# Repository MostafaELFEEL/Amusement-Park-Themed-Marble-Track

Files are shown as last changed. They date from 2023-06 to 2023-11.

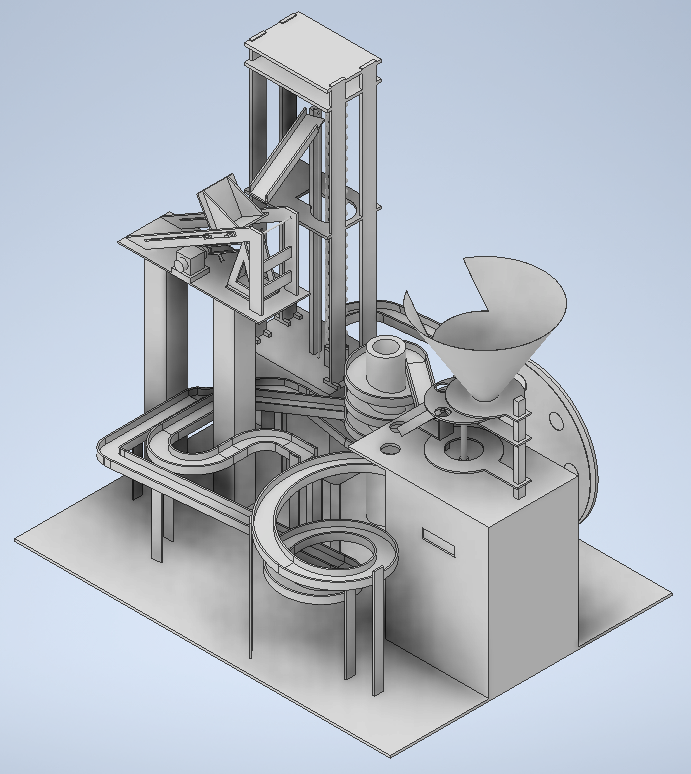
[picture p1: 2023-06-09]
Images of CAD+CAD file/3.PNG

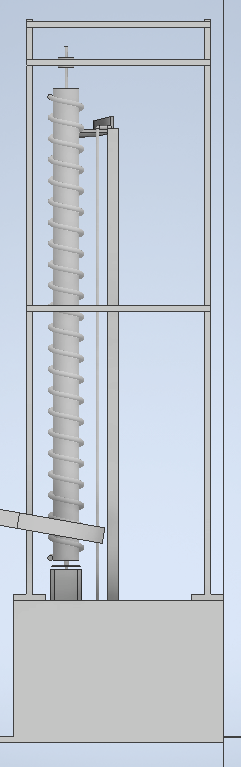
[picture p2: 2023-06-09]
Images of CAD+CAD file/elevator 1.PNG

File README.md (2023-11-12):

# Amusement Park Themed Marble Track
## Kid-Friendly Marble Track Design

Welcome to our exciting marble track, designed especially for kids. This closed-loop game takes the ball on a thrilling journey through various stages, ensuring hours of entertainment.

## Features
1. **Elevator:** The ball is lifted and guided by a fascinating elevator system.
2. **Shooting:** Experience the excitement as the ball is launched from a shooting mechanism.
3. **Sorting:** A sophisticated mechanism, complete with sensors and actuators, automatically categorizes balls into different tracks based on their colors.
4. **Pathways:** The sorted balls travel through engaging pathways, adding an extra layer of fun.

After completing the pathways, the sorted balls are collected and fed back into the elevator system, ensuring continuous enjoyment for the little ones.

## Project Details
For a deeper dive into the project, check out the [Google Drive link](https://drive.google.com/drive/folders/1FEB35v0lif-gc465zCmdioxmccTQT4f7?usp=drive_link) for additional details.

## Watch the Project in Action
- [YouTube Video](https://www.youtube.com/watch?v=VSdp7pH9CCw)
- [Additional Videos](https://drive.google.com/drive/folders/1bEXKJVpvYqGoTFXghtoVNARCpgTNY1nO?usp=drive_link)

Project Image

# CAD Design

CAD Design

Feel free to explore the project and witness the joy it brings to young minds!

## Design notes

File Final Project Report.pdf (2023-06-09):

AIN SHAMS UNIVERSITY
FACULTY OF ENGINEERING

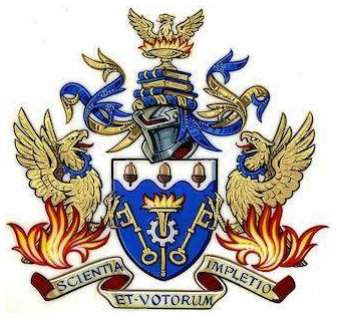
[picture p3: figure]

Mechatronics and Automation Engineering Programs (CHEP) Midterm
- Academic Year 2020/2021

Group 2 Section 1 subsection 2 Team 2
Youssef Khaled Mohamed | 18P2695
Mostafa Ashraf ELFEEL | 18P7611
Mohamed Sherif Shabaan | 18P5784
Youssef Ashraf Ahmed Mohamaden | 18P6536
Mohamed Sherif Mohamed Farid | 18P4006

UEL Module Code
EG8422

UEL Module Name
Machine Design

ASU Course Code
MCT 131

ASU Course Name
Introduction to Mechatronics

Semester
Fall 2020

Date of Submission
21/2/2021

AIN SHAMS UNIVERSITY
I-Credit Hours Engineering Programs (i.CHEP)
2 | P a g e

### Table of Content

I-Credit Hours Engineering Programs (i.CHEP)

3 | P a g e

### Table of figures

### Figure 1 | 6

### Figure 2 | 7

### Figure 3 | 8

### Figure 4 | 9

### Figure 5 | 10

### Figure 6 | 11

### Figure 7 | 12

### Figure 8 | 13

### Figure 9 | 14

### Figure 10 | 15

### Figure 11 | 16

### Figure 12 | 17

### Figure 13 | 20

### Figure 14 | 21

### Figure 15 | 25

### Figure 16 | 26

### Figure 17 | 27

I-Credit Hours Engineering Programs (i.CHEP)

4 | P a g e

### Abstract:

In this report we will discuss final project for MCT 131- introduction to mechatronics. Project details, design, manufacturing of ball sorting mechanism and applying of principles of design such as user experience, mind maps and mood board.

### Introduction:

Our project is a marble track for kids, it is a closed loop game which ball starts at the reservoir or anyplace then it goes through stages which is:

1- Elevator
2- Shooting
3- Sorting
4- Pathways

Ball sorting mechanism is designed to sort balls of 3 different colors into 3 different tracks by way of automatic system containing sensors and actuators.
The balls are then collected through pathways and fed into elevator system which lifts and guides the balls into a shooting mechanism. Then the balls after being shot are caught and delivered to sorting mechanism which sorts them, and the loop continue.

This was a brief overview of the game.

### Research

We got most of our ideas from asking older students and from these links: https://www.youtube.com/watch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 (https://howtomechatronics.com/tutorials/arduino/arduino-dc-motor-control-tutorial-l298n-pwm-h-bridge/)

I-Credit Hours Engineering Programs (i.CHEP)

5 | P a g e

### Work Planning

We divided the project into 3 stages…

Stage 3: Calibrating and Finishing

Upon completion of each mechanism, we started putting it together and calibrating

each mechanism to fit into the project. Then we started decorating the project to fit

into our theme

Stage 1: Brainstorming

We decided to brainstorm a general design that includes size, general positioning,

and an abstract flow of mechanisms.

Stage 2: Main Work Process

Then we started detailing and designing each mechanism separately but considering

the general design.

Stage 4: Integrating

After individually finishing each part we started working on integrating all parts

with each other

I-Credit Hours Engineering Programs (i.CHEP)

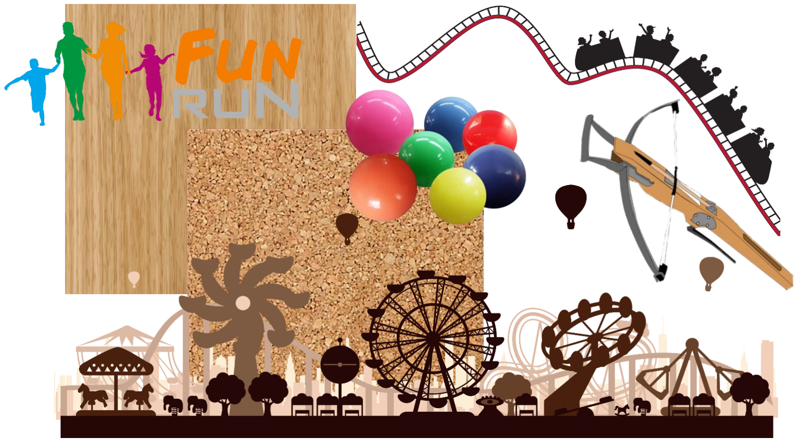
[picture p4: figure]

6 | P a g e

### Design and Theme

Theme:

Our chosen theme is “Amusement park” as this theme would provide us with several design ideas that would fit our project requirements.

Mood board:

Fig. 1: mood board design

I-Credit Hours Engineering Programs (i.CHEP)

7 | P a g e

Mind Map:

Minimum hight

2 Mechanisms

Strength

Target

3 way sorting | Match theme
| Match color of balls

Fig. 2: Mind map design

I-Credit Hours Engineering Programs (i.CHEP)

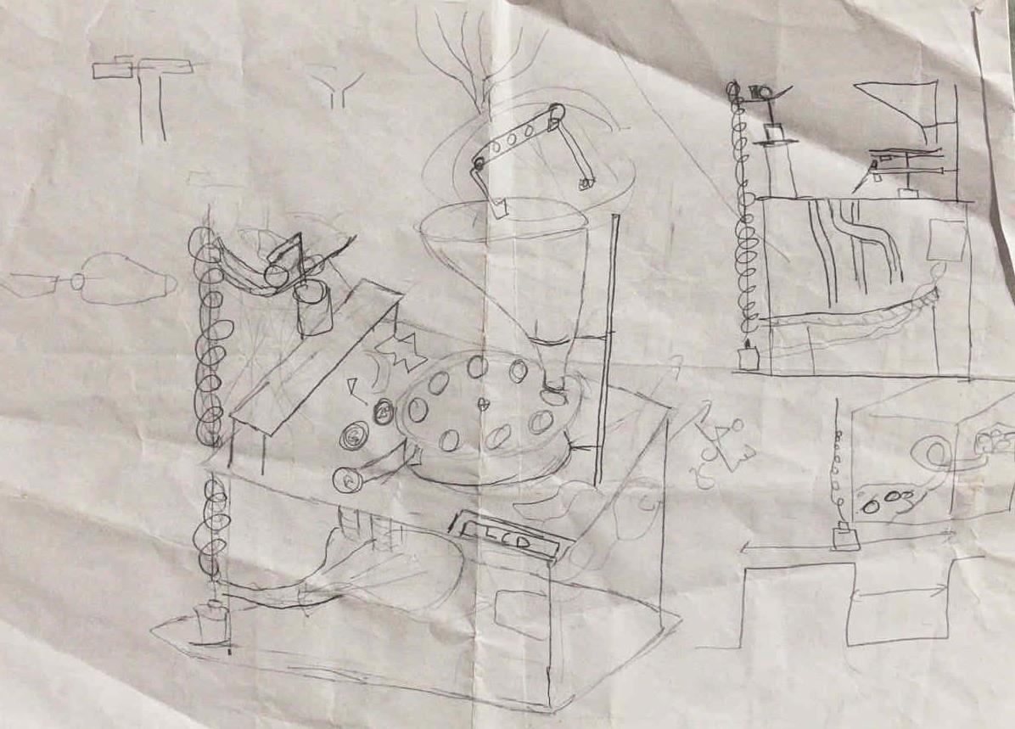
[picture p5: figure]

8 | P a g e

Fig. 3: image of draft drawing

First Draft of the general design:

We used this draft as a starting point to picture the positioning, size, theme and mechanisms.

I-Credit Hours Engineering Programs (i.CHEP)

9 | P a g e

Sketches:

Fig. 4-1: sketch of shooting mechanism

Fig. 4-2: sketch of lifting mechanism

Fig. 4-3: sketch of sorting mechanism

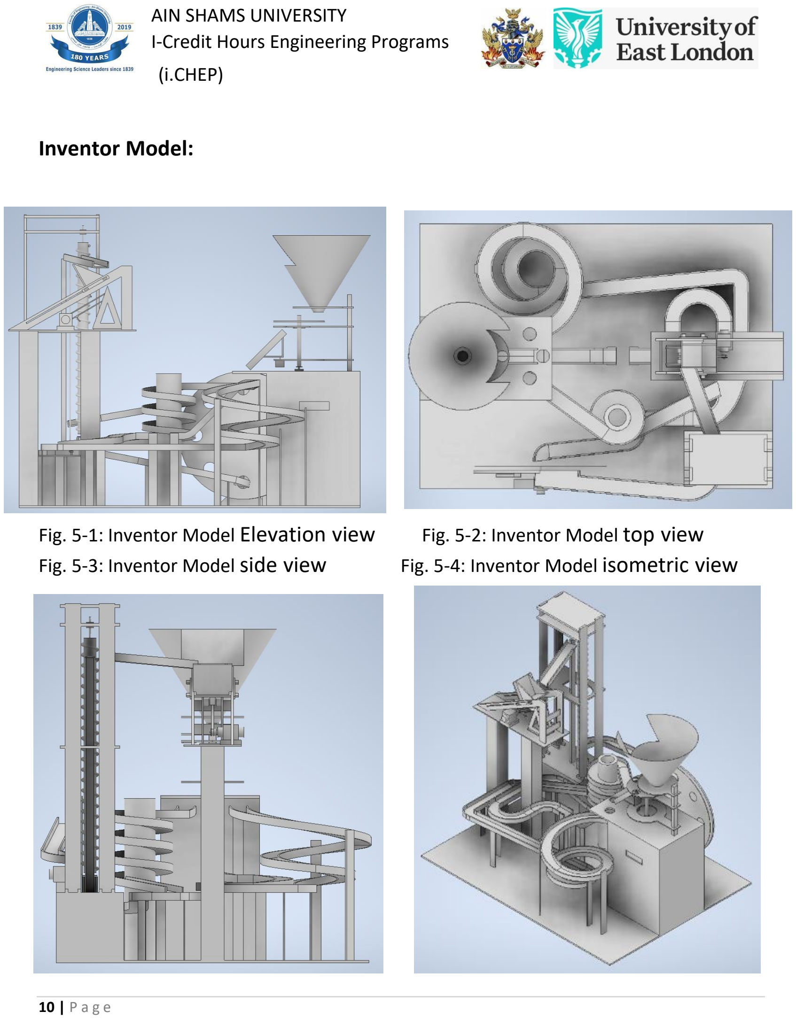
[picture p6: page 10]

I-Credit Hours Engineering Programs (i.CHEP)

10 | P a g e

Inventor Model:

Fig. 5-1: Inventor Model Elevation view | Fig. 5-2: Inventor Model top view
Fig. 5-3: Inventor Model side view | Fig. 5-4: Inventor Model isometric view

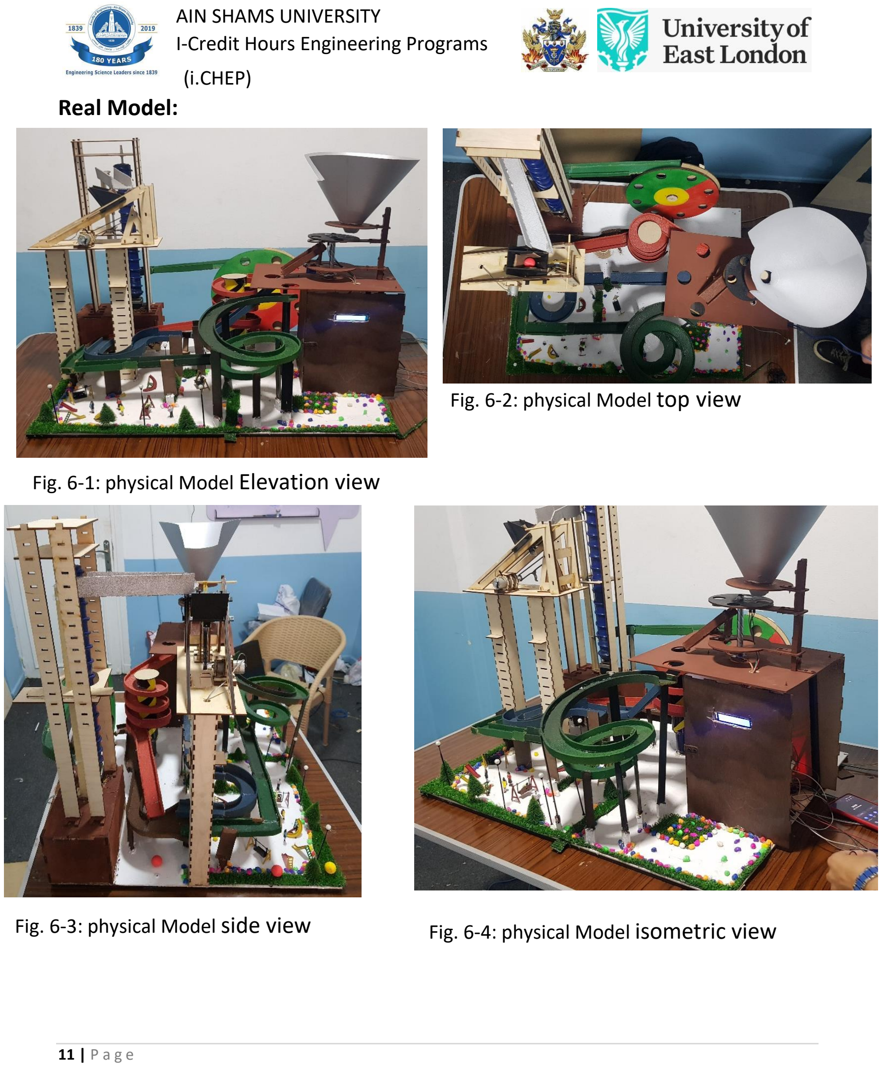
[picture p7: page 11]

I-Credit Hours Engineering Programs (i.CHEP)

11 | P a g e

Real Model:

Fig. 6-2: physical Model top view

Fig. 6-1: physical Model Elevation view

Fig. 6-3: physical Model side view | Fig. 6-4: physical Model isometric view

I-Credit Hours Engineering Programs (i.CHEP)

12 | P a g e

### Mechanisms

For the mechanisms of the project, it all starts at a reservoir which is located at the lowest point (brown pathway).

Then it moves on to…

1- Lifting Mechanism:

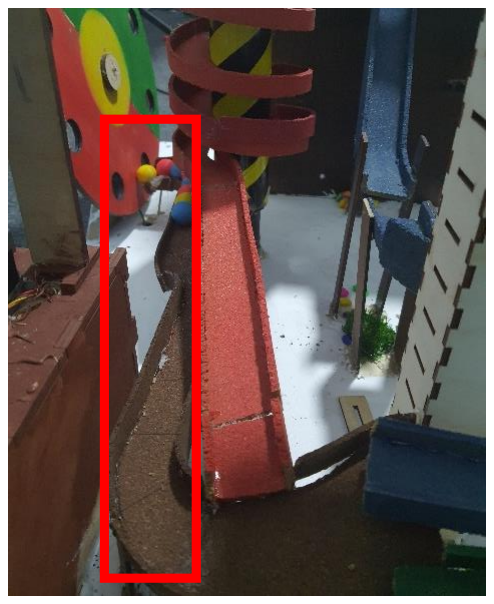
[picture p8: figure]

We got 2 different lifting mechanisms integrated in this project...
1) Circular elevator

The elevator receives the ball in one of its groves then moves it up in a circular motion. The ball stays in grove because of a back support and upon arriving to the top there is no support. Therefore, the ball falls on the dedicated pathway to the 2nd lifting mechanism.

Fig. 7-1: reservoir

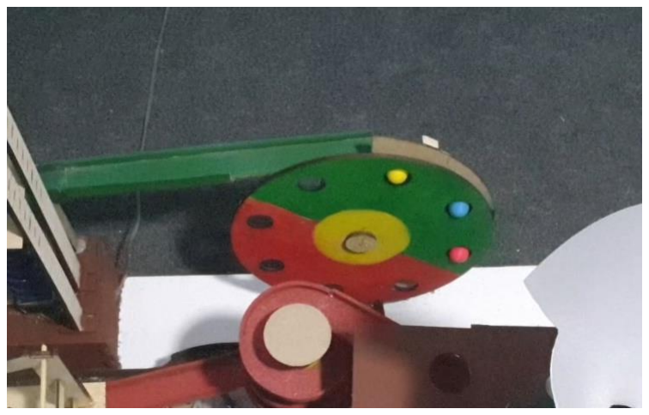
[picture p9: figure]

Fig. 7-2: circular elevator

I-Credit Hours Engineering Programs (i.CHEP)

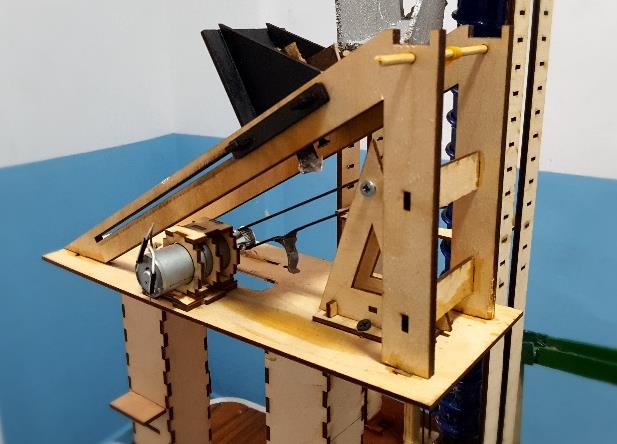
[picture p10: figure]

13 | P a g e
2) Spiral elevator

The elevator receives the ball at the bottom and pushes it up by the spiral between it and metal rail until the top where it falls out onto a track to take it to shooting mechanism. The ball is kept on the spiral as it continues motion and only falls out at the top where the rails end.

2- Shooting:

Our shooting mechanism is inspired by crossbow mechanism where a motor moves a belt that pulls a small cart backwards and on release the cart is sling shot due to elastic bands. The shooting is aimed at the funnel at the start of the sorting mechanism.

Fig. 8-1: spiral elevator | Fig. 8-2: drawing of spiral elevator

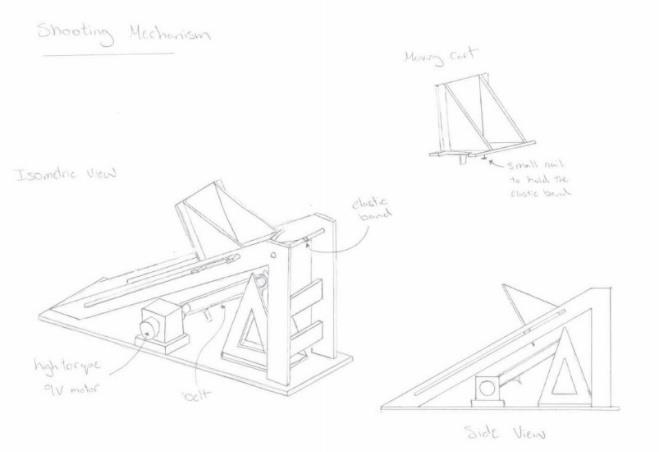
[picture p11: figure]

Fig. 8-3: shooting mechanism | Fig. 8-4: drawing of shooting mechanism

I-Credit Hours Engineering Programs (i.CHEP)

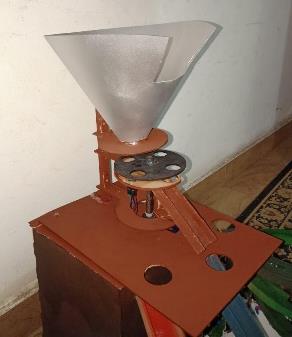
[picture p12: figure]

14 | P a g e

3- Sorting:

Our sorting mechanism works by first catching a ball with funnel connected to the upper plate. The cone funnels the ball into a hole in a plate connected in the middle with a metal shaft which is connected to a 180-degree servo motor (sg 90 micro servo) connected to the base of sorting mechanism. The ball rolls on the middle plate on which the color sensor is fixed under an acrylic window, after the ball falls into the hole in the moving plate the plate first moves 90 degrees to put the ball in front of the color sensor which detects color of the ball.

Then the servo moves another 90 degrees dropping the ball through a hole in the middle plate onto a ramp connected to another micro servo which moves to drop the ball onto one of the three tracks through one of three holes in the base of the sorting mechanism. The holes are at 18, 90 and 150 degrees for red, blue and green tracks respectively. The ramp is connected directly to another servo which is fixed on a lower plate. All plates are connected to a wooden shaft through a slot at the back and fixed with metal L shape and screws. The wooden shaft is connected to the base with metal L shape and screws.

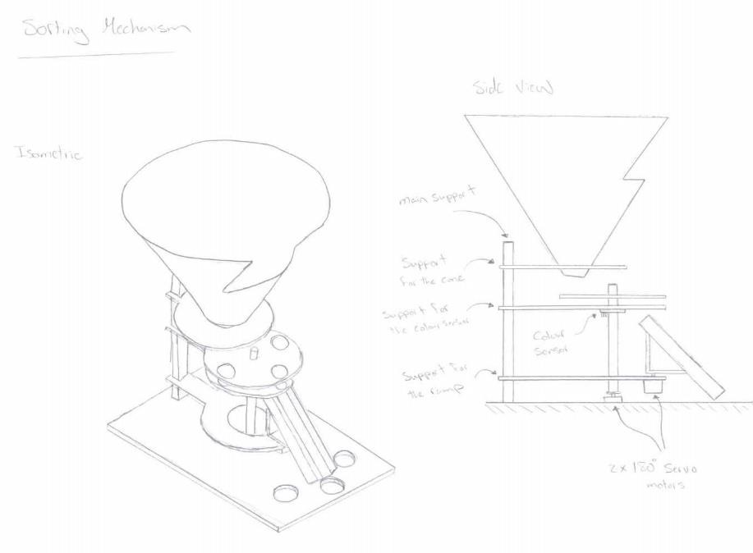
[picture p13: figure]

Fig. 9-1: sorting mechanism | Fig. 9-2: drawing of sorting mechanism

I-Credit Hours Engineering Programs (i.CHEP)

15 | P a g e

4- Pathways:

The tracks were designed to maintain the fun part of the park to the child, the three tracks are similar to the playground slides but in many shapes, to provide happiness, joy and pleasure to the kid who is playing.
To make the tracks in the way we desired -to be like the amusement park- there were specified requirements in the material we need:
1- Soft because there are many curves in the tracks.
2- Safe material for the children
So, we decided to use cork as it is a safe material for the children and to be able to do the track with its curves.

### 5- LCD:

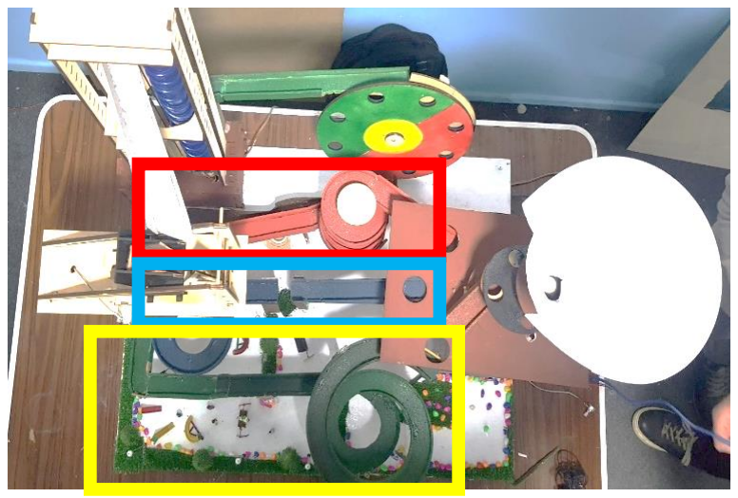
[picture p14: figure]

Depending on the ball color the LCD counts each color that paths from sorting mechanism to pathways.
The LCD gives a purpose for the whole cycle.

Fig. 10-2: drawing of tracks.

Fig. 10-3: LCD screen

Fig 10-1: tracks

I-Credit Hours Engineering Programs (i.CHEP)

16 | P a g e

### Manufacturing

During manufacturing we used several tools and processes to save time, money and have a high-quality product.
These considerations also affected our material selection.
Our project was mainly manufactured using 3 mm thick plywood that was laser cut and cork sheet cut by hand and put together using hot glue.

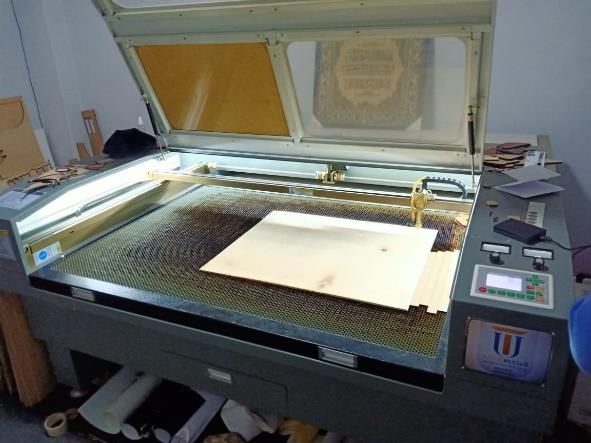
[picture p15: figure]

1) We used laser cutting plywood due to its low price,
very high accuracy, and speed of manufacturing. It allowed us to prototype more easily and helped us keep costs down while using
good parts.

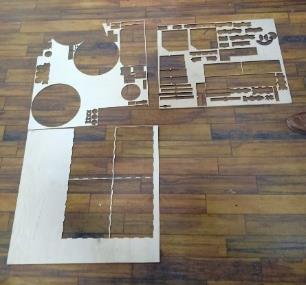
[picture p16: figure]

2) We used cork for our pathways for its flexibility and ability to bend without breaking, we also used it due to its ability to be cut with simple workshop knife and glued together with hot glue easily

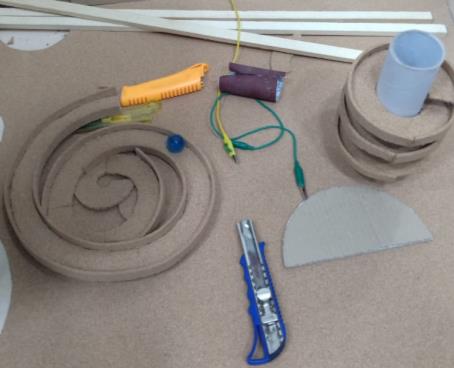
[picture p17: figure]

3) We also used multiple hand tools and power tools in making our product.

Fig. 11-1: laser cutting

Fig. 11-2: laser cutting machine

Fig. 11-3: cork

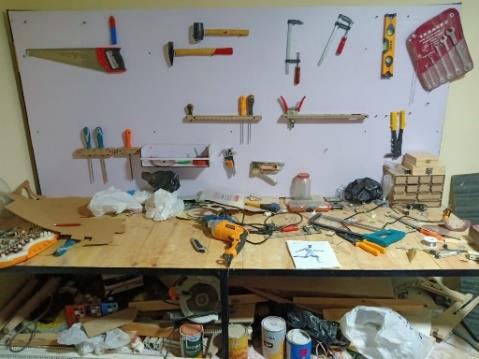
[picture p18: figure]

Fig. 11-4: hand tools | Fig. 11-5: work bench

I-Credit Hours Engineering Programs (i.CHEP)

17 | P a g e
4) For painting our project, we used both acrylic paint and spray cans.
5) In assembling our project, we used a wide range of fixation methods.
- We used two-part epoxy, super glue and screws with steel L shape in parts that needed high strength, such as shooting mechanism.
- We used hot glue in parts that required a lot of adjustment such as the tracks.
6) Finally, we used several measuring devices in construction of our project to ensure accuracy of dimensions and fits (aristo, Vernier caliber). We also used multi-meter to test and trouble shoot our electronic.

Fig. 12-1: paint

Fig. 12-2: steel L
shape and screws

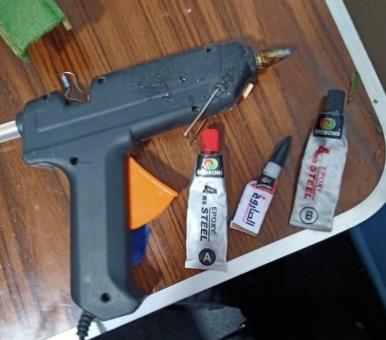
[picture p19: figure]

Fig. 12-3: super
glue and hot glue

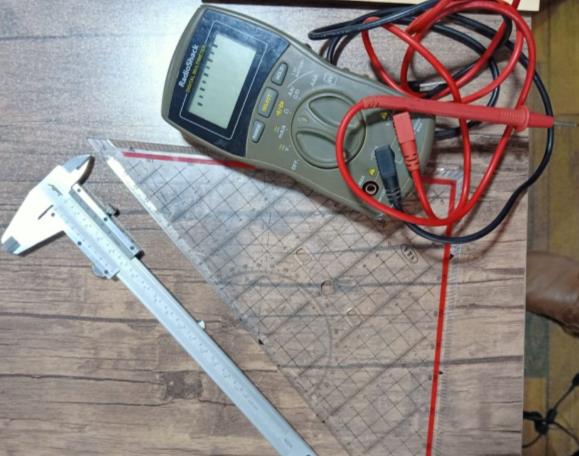
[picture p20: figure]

Fig. 12-4: measuring devices

I-Credit Hours Engineering Programs (i.CHEP)

18 | P a g e

### Electrical Design

Our goal in this project was to implement all what we have studied in this course in one project with minimum complications.

Our system consists of:

- 2 servo motors (1.5k/180°).
- 1 stepper motor (nema17).
- 2 dc motors (high torque 3-9v).
- 1 color sensor.
- 2 H-bridges.
- Micro controller ARDUINO MEGA.
- Lcd screen
- Power supply 8.5A 12V

We have managed to combine all different types of motors in one project to gain experience in wiring all different systems.

Wiring: we put in our considerations that this is a children friendly game, all wires are sealed and run under the base of the game to be safe away from any users, we designed an electric box which contain all of the components and sealed from all corners, designed a power supply box which is hidden under the elevator.

Controlling different motors:

As we mentioned our system consists of different majority of motors.

Controlling dc motors:

We used H-bridge L298N to control the two motors direction and speed.

Note: our dc motors are 3-9v where our supply is a 12v so from the driver we can regulate the voltage via PWM.

I-Credit Hours Engineering Programs (i.CHEP)

19 | P a g e

Controlling stepper motor:

We have managed to control a stepper motor with a L298N to cut expenses and it’s much more reliable.

Controlling servo motors:

Actually, servo motors are very simple to control where it has 3 wires one +5V one GND and the last is the input for the Arduino.

LCD screen:

We managed to make our game user friendly by adding a screen which displays the amount and the color of balls thrown to the cone.

Combining electric systems:

Our wiring system is simple and functional, we decided to use one Arduino mega which benefits of 53 pins to control the system which is much better and cheaper than using 2 or 3 UNOs.

Wiring color code:

All BROWN wires are GND.

All BLACK wires are GND.

All RED wires are +5V.

All BLUE wires are +12V.

ALL YELLOW wires are consisted for sensors output/input.

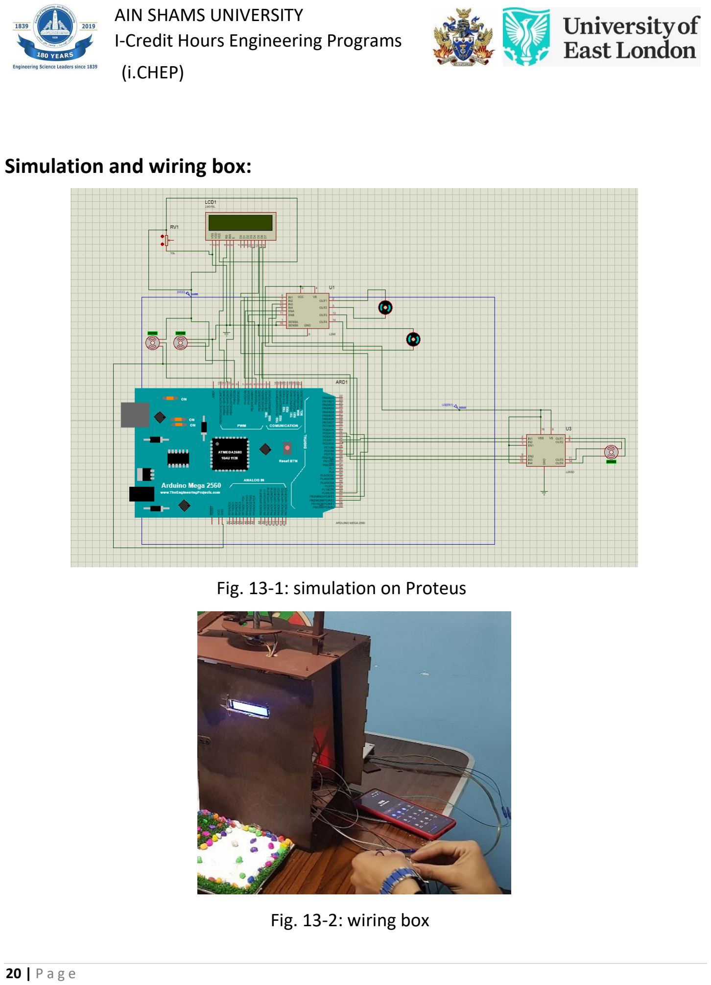
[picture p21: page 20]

I-Credit Hours Engineering Programs (i.CHEP)

20 | P a g e

Fig. 13-2: wiring box

Simulation and wiring box:

Fig. 13-1: simulation on Proteus

I-Credit Hours Engineering Programs (i.CHEP)

21 | P a g e

### Programming

-Software flowchart

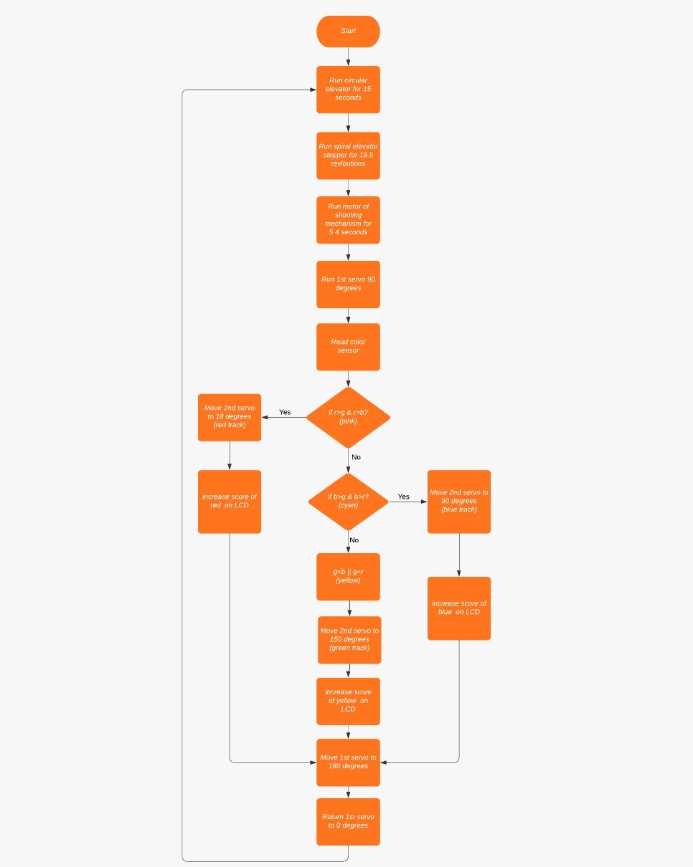
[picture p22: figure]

Fig. 14-1: software flow chart

I-Credit Hours Engineering Programs (i.CHEP)

22 | P a g e

Controlling stepper motors:
To control the stepper motors I included a library STEPPER.h
#include <Stepper.h>

Stepper motors are controlled via pulses to its coils so to control its speed and rpm we declare a library which is called mystepper:
Stepper myStepper = Stepper(stepsPerRevolution, 34, 35, 32,33);
To control stepper motor speed:
myStepper.setSpeed(42)
To control number of rpms the stepper will rotate:
Note: nema17 is stepper motor which 200 pulses makes a fully revolution so if we took 3900/200 its 19.5 rpm in every cycle.
myStepper.step(-3900);
Controlling DC motors:
First we have to understand that controlling a dc motor with a driver consists of three main wires to the microcontroller which are IN1 IN2 ENABLE.
If IN1 and IN2 are HIGH the motor is stopped.
If IN1 is low and IN2 is HIGH the motor rotates in a clockwise direction and vice versa. ENABLE controls the speed of the motor via PWM pin.
The code for the motor in charge of the shooting mechanism:
//For Clockwise motion , in_1 = High , in_2 = Low
analogWrite(pwm,190);
digitalWrite(in_1,HIGH) ;
digitalWrite(in_2,LOW) ;
delay(3000);
digitalWrite(in_1,HIGH) ;
digitalWrite(in_2,HIGH) ;

I-Credit Hours Engineering Programs (i.CHEP)

23 | P a g e

The code for the motor in charge of the wheel elevator mechanism: analogWrite(pwm,35);
digitalWrite(in_3,HIGH) ;
digitalWrite(in_4,LOW) ;
delay(3000);
digitalWrite(in_3,HIGH) ;
digitalWrite(in_4,HIGH) ;
Sorting :
To do sorting we rely on servo motors that can give specific angles we use them to position balls above color sensor accurately and to change which track the ball goes to based on color detected
selector.write(18);
we also loops to move steeper in pricis speed as well as angle

color sensor gives different values of red green and blue light and we can compare them to determine color of ball

I-Credit Hours Engineering Programs (i.CHEP)

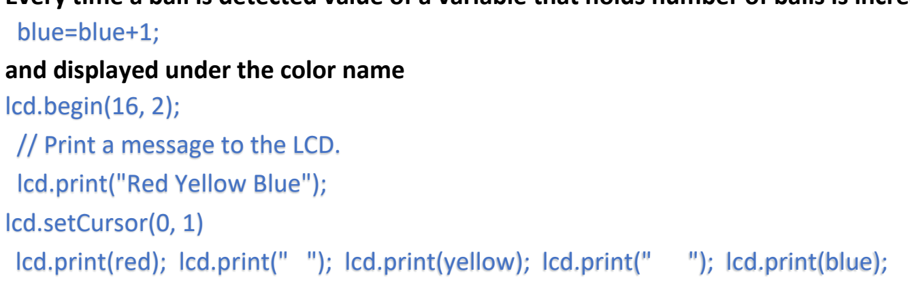
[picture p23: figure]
blue=blue+1; and displayed under the color name lcd.begin(16, 2); // Print a message to the LCD. lcd.print("Red Yellow Blue"); lcd.setCursor(0, 1)

24 | P a g e

LCD screen and sorting:
We use a LCD screen to display number of balls of each color that is detected

Every time a ball is detected value of a variable that holds number of balls is increased

lcd.print(red); lcd.print(" "); lcd.print(yellow); lcd.print(" "); lcd.print(blue);

Implementation of all systems:

Our system implementation idea is step by step stages where every stage finishes the next starts, we implemented the ideal delay time between systems by calibration.

We found that delaying time is simpler and more reliable than putting 3 more sensors in the system .

I-Credit Hours Engineering Programs (i.CHEP)

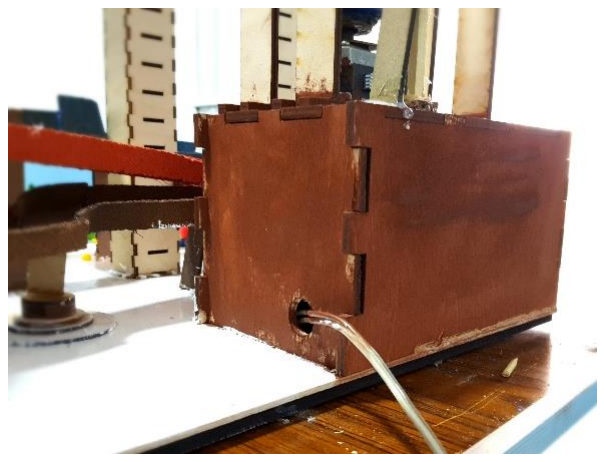
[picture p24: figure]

25 | P a g e

### Calibration and Safety Consideration

- Calibration (integration):
The method used into bringing all the mechanisms together is “try and error” method. Where we adjusted position, power, and angles needed for all mechanisms for it to operate correctly.
- Safety Considerations:

As this is a children’s toy, we:
- Used materials which are soft and safe.
- Avoided any Sharp edges by chamfering.
- Grinded all pointed nail ends.
- Limited visible wires as much as possible by making the base 2 layers of wood to allow all wiring to move underneath.
- Made boxes for both power supply and electronics to avoid noise and keep it away from reach.

Fig.15-1: Separated power
supply box

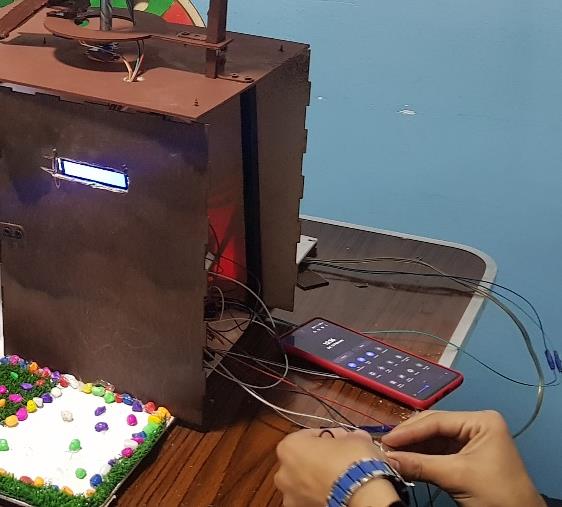
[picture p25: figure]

Fig.15-2: All wires comes from underneath the base and into the electronics box

I-Credit Hours Engineering Programs (i.CHEP)

26 | P a g e

### Costs and Bills

NAME | PRICE | NO, OF | TOTAL COST
SG-90 MICRO SERVO | 65 | 2 | 130
WOOD | -- | -- | 140
JUMPERS (ALL TYPES) | 1 | 60 | 60
ARDUINO MEGA 2560 R3 | 220 | 1 | 220
MINI BREADBOARD | 12 | 1 | 12
3-9 VOLT DC METAL GEARBOX MOTOR | 150 | 2 | 300
RGB COLOR SENSOR - TCS34725 | 99 | 1 | 99
CORK (4MM) | 80 | 1 | 80
CORK (3MM) | 60 | 1 | 60
H BRIDGE L298 | 55 | 2 | 110
SPRAY PAINT | 20 | 5 | 100
LASER CUTTING | 150 | -- | 150
LCD SCREEN 16 CHAR.X2 LINES | 35 | 1 | 35
SUPER GLUE | 2.5 | 10 | 25
USED NEMA 17 STERPER MOTOR | 15 | 1 | 15
PROPS | -- | -- | 100
ACRYLIC PAINT | 35 | 2 | 70
POWER SUPPLY | 110 | 1 | 110
| | TOTAL | 1,816 EGP

Fig.16: bill of materials

### Bills available:

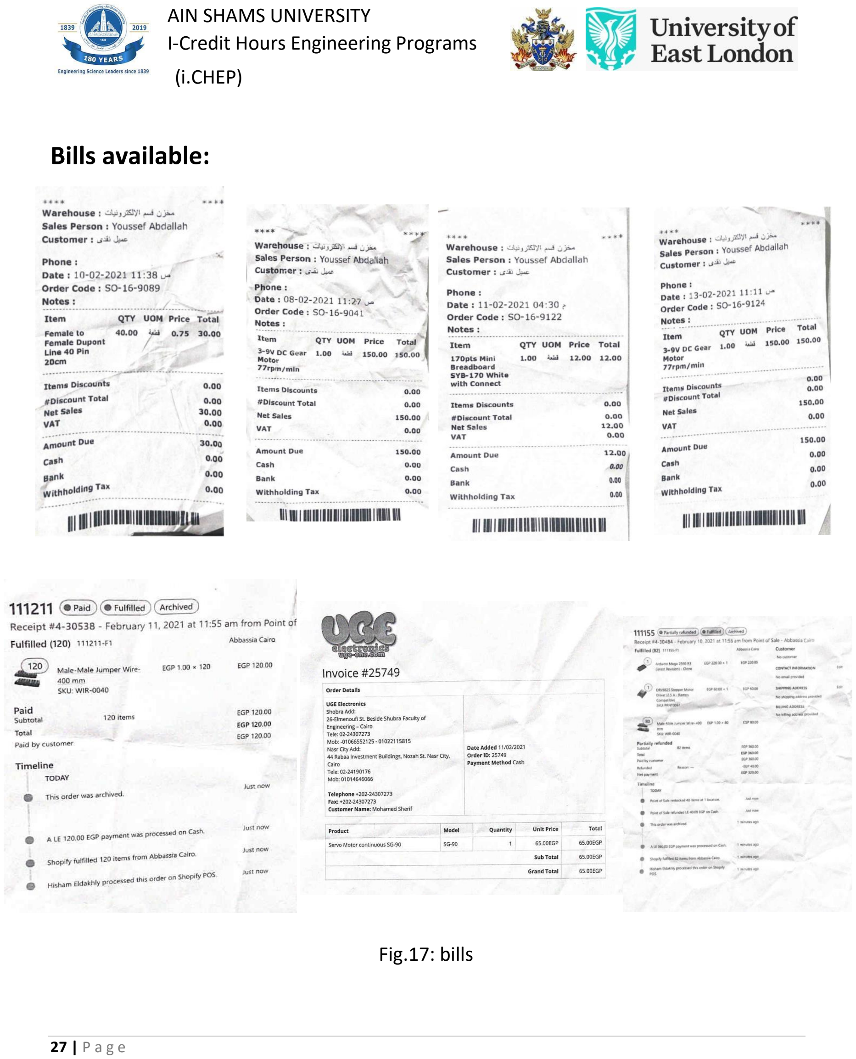
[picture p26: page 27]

I-Credit Hours Engineering Programs (i.CHEP)

27 | P a g e

Fig.17: bills

I-Credit Hours Engineering Programs (i.CHEP)

28 | P a g e

### Contribution

- Youssef Khaled Mohamed

Main Tasks:

- Came up with the general design.
- Mechanisms Manufacturing and Assembly.
- Mechanisms Calibration.
- Wiring passages.
- Team coordination.
- Report.

Side tasks:

- Sketches.
- Decorating for the theme.
- Safety considerations.
- Spiral elevator design and manufacturing.

I-Credit Hours Engineering Programs (i.CHEP)

29 | P a g e
- Mohamad Sherif shaaban

Main Tasks:

- Electrical design and simulation
- Responsible for coding stepper motor, dc motors ,sorting function , full system implementation
- Wiring and sorting all systems
- Design of Shooter
- Design of elevator Stand
- Design of sorting
- design of Power supply box
- Code Calibration.

Side tasks:

- Assembly of shooting
- Painting

I-Credit Hours Engineering Programs (i.CHEP)

30 | P a g e
- Youssef Ashraf Ahmed Mohamaden

Main Tasks:

- Pathways Design.
- Manufacturing of pathways
- Implementation of pathways
- Design of circular elevator
- Painting
- Testing final stages
- Decoration of the theme

Side tasks:

- Wiring
- Implementation of circular elevator
- Calibration of mechanical systems
- Documentation

I-Credit Hours Engineering Programs (i.CHEP)

31 | P a g e
- Mostafa Ashraf Ebrahim Ali ELFEEL

Main Tasks:

- Full project 3D Modelling on inventor.
- Pathways Design.
- Manufacturing of pathways.
- Implementing pathways.
- Implementing circular elevator.
- Photographer.
- Testing final stage.

Side tasks:

- Calibration of sorting mechanism.
- Came up with sorting idea (comparing between colors directly rather than using color ranges in if conditions).
- Integrating LCD code with sorting code.
- Software flow chart.

I-Credit Hours Engineering Programs (i.CHEP)

32 | P a g e
- Mohamed Sherif Farid

Main Tasks:

- Color sensor and sorting code
- Calibration of sorting mechanism
- Design of adjustable supports for shooting mechanism
- Design of motor support in shooting mechanism and circular lifter
- Design and manufacturing of cone in sorting

Side tasks:

- Painting
- Documentation
- Finding and acquiring electrical parts

I-Credit Hours Engineering Programs (i.CHEP)

33 | P a g e

## Documentation links

Here is the drive links of all the documents we have made.

- Inventor files
https://drive.google.com/drive/folders/1FrTpmw0FraUCRafljQq114bz1Z9cbjgx?usp=sharing (https://drive.google.com/drive/folders/1FrTpmw0FraUCRafljQq114bz1Z9cbjgx?usp=sharing)
- Arduino code
https://drive.google.com/drive/folders/1scHzKKI9R1HsBMGQeQhna90Tq-H8yCTF?usp=sharing (https://drive.google.com/drive/folders/1scHzKKI9R1HsBMGQeQhna90Tq-H8yCTF?usp=sharing)
- Proteus files
https://drive.google.com/drive/folders/16ooY_BuQNRhmfbX2FgmfHXhDXMu7TFTg?usp=sharing (https://drive.google.com/drive/folders/16ooY_BuQNRhmfbX2FgmfHXhDXMu7TFTg?usp=sharing)
- Video of project
https://drive.google.com/drive/folders/1bEXKJVpvYqGoTFXghtoVNARCpgTNY1nO?usp=sharing (https://drive.google.com/drive/folders/1bEXKJVpvYqGoTFXghtoVNARCpgTNY1nO?usp=sharing)

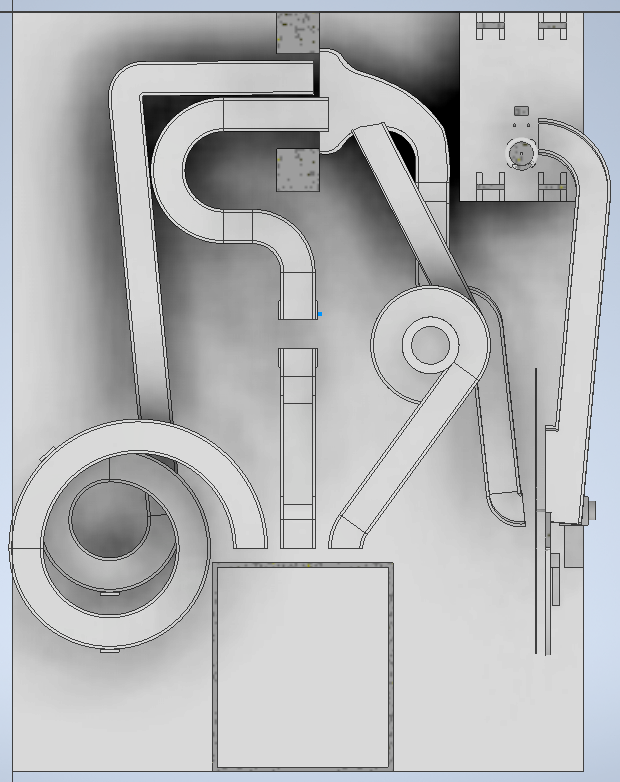
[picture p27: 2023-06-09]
Images of CAD+CAD file/track 0.PNG

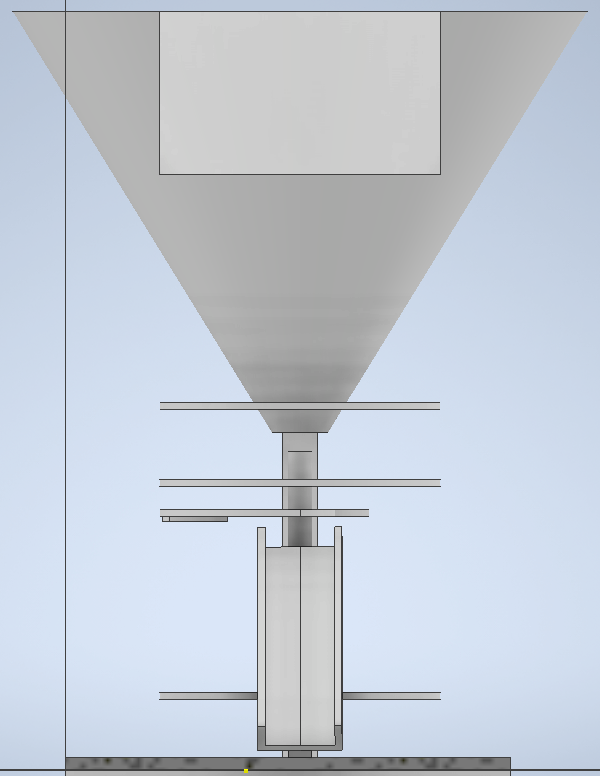
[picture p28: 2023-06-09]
Images of CAD+CAD file/sorting system 2.PNG

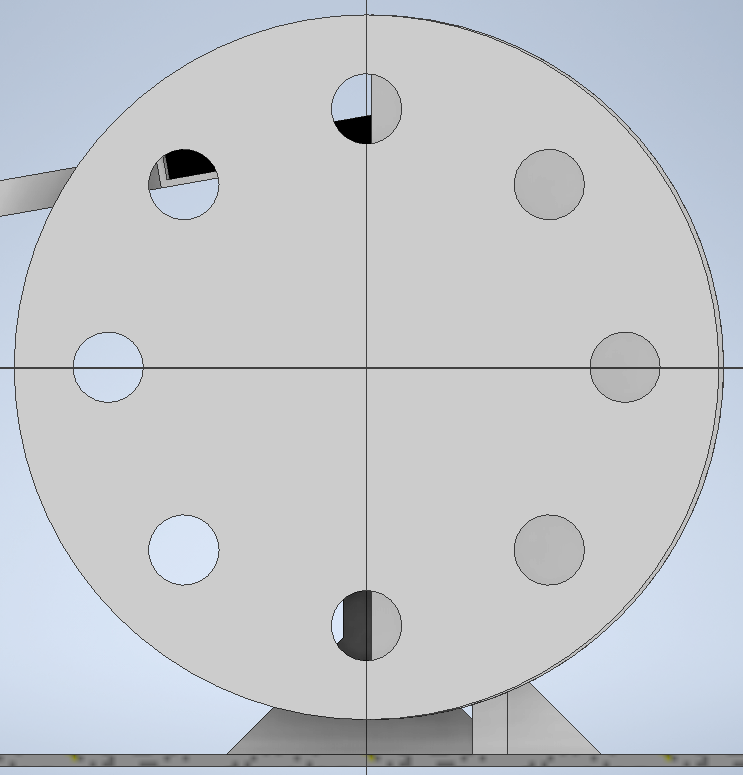
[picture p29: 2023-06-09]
Images of CAD+CAD file/wheel 0.PNG

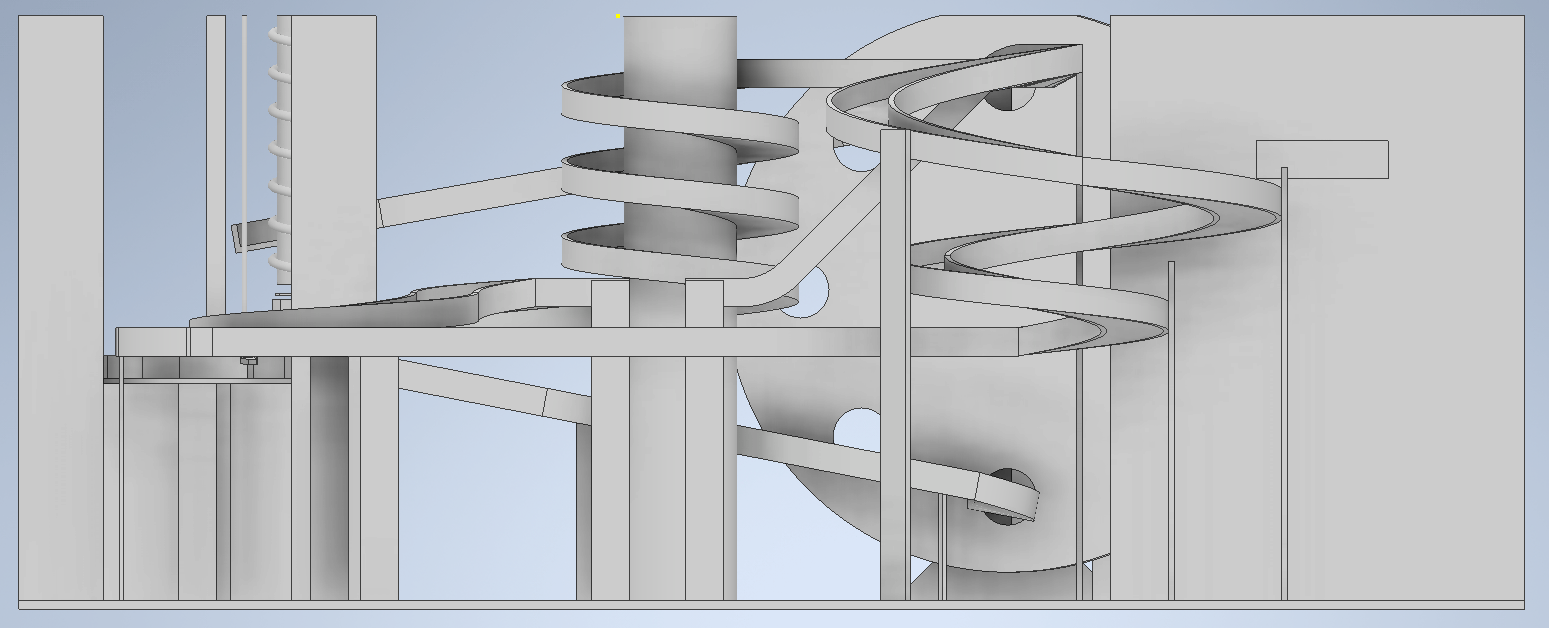
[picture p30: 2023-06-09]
Images of CAD+CAD file/track 3.PNG

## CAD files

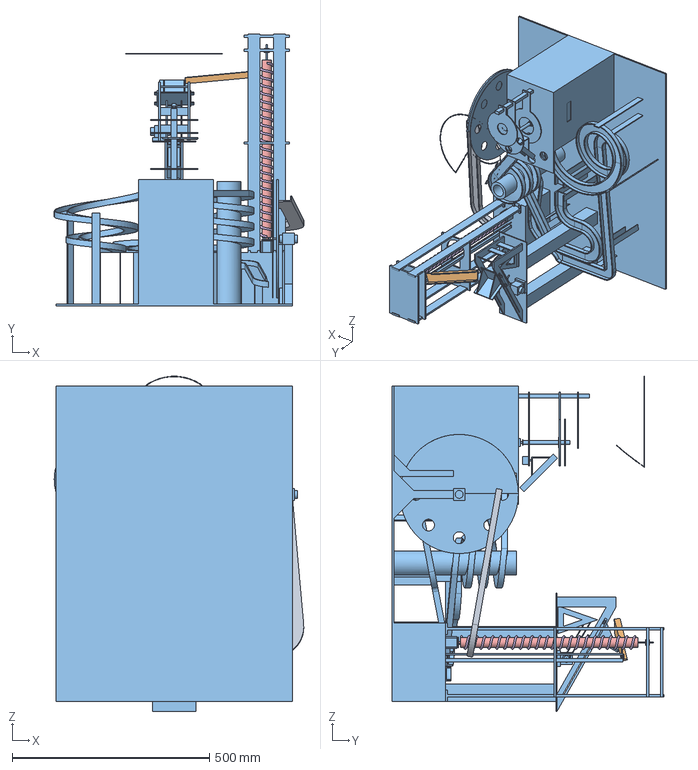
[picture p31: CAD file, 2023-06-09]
Images of CAD+CAD file/important.stp
632.8 x 689.0 x 849.4 mm

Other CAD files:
Images of CAD+CAD file/important.ipt
